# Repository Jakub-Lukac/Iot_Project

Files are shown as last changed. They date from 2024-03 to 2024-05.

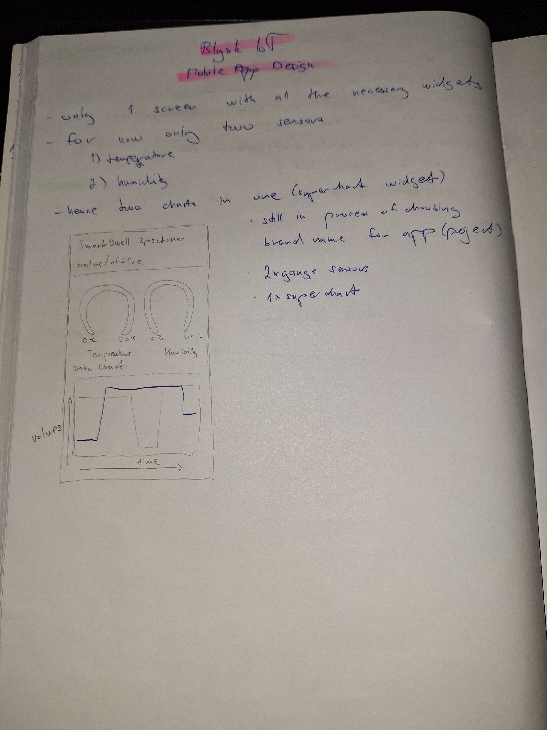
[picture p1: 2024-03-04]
MobileAppDesign/Mobile_App_Files/Low Fidelity.jpg

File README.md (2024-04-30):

# Iot_Project
Arduino and Blynk Project

# Repository structure
As a team, we decided that his GitHub repository would be used for both code as well as all the other documentation like pictures, notes, etc.
It will consist of two folders, Code and Documentation.

# Introduction
The device addresses the need to monitor and maintain quality living conditions in university accommodations and homes, aiming to prevent issues like mold growth. It also benefits elderly individuals living in cold homes by improving their health and social well-being.

# Project Solution
The project creates a room monitoring system for living spaces lacking environmental monitoring. It tracks temperature, humidity, and light levels using microcontrollers and physical sensors, with a screen and optional mobile app for accessibility. Resources are openly available on GitHub for collaboration and transparency.

# Project Requirements
•	Measure temperature.
•	Measure humidity.
•	Measure air quality index.
•	Connect and send data through any specified Wireless connection (Wi-Fi), including eduroam (WPA2 Enterprise).
•	Display current state through display located on the front of the console.
•	Display current state through mobile application

# Reference List
Noëlle Cotter, Eugene Monahan, Helen McAvoy, Patrick Goodman 2012, ‘Coping with the cold – exploring relationships between cold housing, health and social wellbeing in a sample of older people in Ireland’ emerald [Online]. Available from: https://www.emerald.com/insight/content/doi/10.1108/14717791211213607/full/html
[Viewed 8 March 2024]. 
Ahmad Roihan, Ferry Sudarto, Trengginas Cahyo Putro 2018, ‘Internet of Things on Monitoring and Control System in Server Area’ ieeexplore [Online]. Available from: https://ieeexplore.ieee.org/abstract/document/8549759
[Viewed 8 March 2024].

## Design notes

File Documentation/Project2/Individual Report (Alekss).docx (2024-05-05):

Atlantic Technological University, Sligo

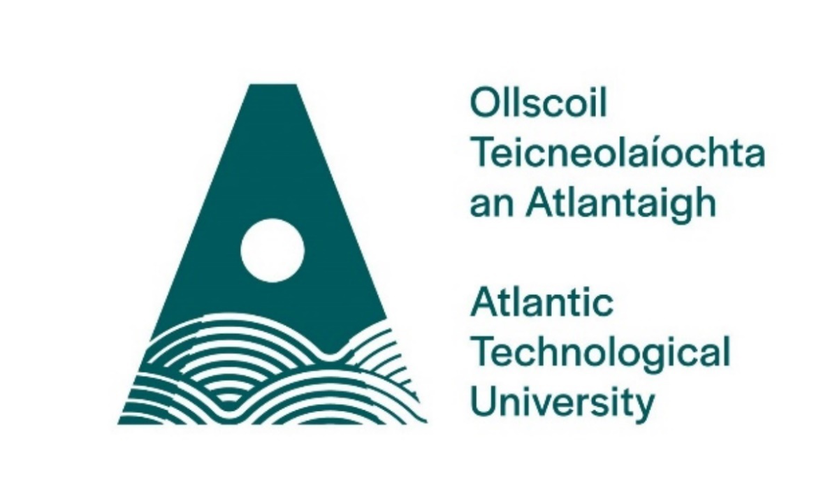
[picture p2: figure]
Obrázok, na ktorom je text, vizitka, snímka obrazovky, písmo Automaticky generovaný popis

# Individual Report

Name: Alekss Belavskis

Student ID: S00253368

Email: s00253368@atu.ie

Course: BSc in Software Development L8

Year: 1

# 1. Team Role:

In my group for Project 2, my main objective was to upgrade the code we used in Project 1. Between project 1 and project 2, we decided to change from using the Arduino Yun to the ESP32 because of its smaller and greater performance.

I continued to use the Arduino IDE during the coding process of the ESP32 for Project 2, as it worked very similarly to the Arduino, aside from some minor code changes. I found Visual Studio to be less clear-cut to setup when working with the ESP32.

I also ended up modifying the previously used Python script for generating the RGB LCD’s colour by adding a cubic interpolation function which addressed some issues with colour transitions, but this feature never ended up being implemented in the ESP code due to the language differences between Python and C.

# 2. Problems Faced:

With project 2, as we decided to use the ESP32 instead of the Arduino Yun, I needed to spend some time adjusting to and learning about how the ESP32 works and how to write code for it. Overall, the code way you write code is very similar for both chips, but there are different libraries required. I also experimented with Visual Studio, but settled with Arduino IDE as it was easier to set up. After adjusting to the small differences in how the ESP works compared to the Arduino Yun, I was ready to add more features to the room monitor.

During my time adding new features to the room monitor, I faced several coding problems I’d eventually come to solve. For example, when I added the functionality of the button to make the display change between showing the temperature and the air quality. I hadn’t initially realized that the button’s state only changed from 0 to 1 while the button was pressed, instead of toggling between 0 and 1 after being pressed and released. I fixed this functionality using logic that compares the current button state to the previous button state. This works by toggling the LCD state only when the last button state and current button state are different.

# 3. Overall Reflection:

I found using GitHub to be very helpful in relation to the coding process. There were times where I wanted to revert part of my code to a previous state, and I could easily do so by looking at previous commits. It also helped us to share our documentation and keep it up to date while we worked on it.

We found that the Arduino Yun did not have very reliable Wi-Fi, because it oftentimes wouldn’t recognize the network I was trying to connect to, and switching to the ESP32 solved this problem. It was much easier to connect to Wi-Fi using the ESP32 in general, and I later found out with some experimenting that it was possible to connect the ESP32 to ‘eduroam’, a WPA2-Enterprise network, using my college credentials. (These credentials were kept safe using a ‘.gitignore’ file)

In conclusion, I’ve really enjoyed working with my group towards a common, and I’m overall satisfied with the product that we created. In the future I’d like to revisit this product idea in my own time to polish it and possibly improve it.

Academic Year: 2023/2024

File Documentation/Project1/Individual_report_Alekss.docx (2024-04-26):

Atlantic Technological University, Sligo

Obrázok, na ktorom je text, vizitka, snímka obrazovky, písmo Automaticky generovaný popis

# Individual Report

Name: Alekss Belavskis

Student ID: S00253368

Email: s00253368@atu.ie

Course: BSc in Software Development L8

Year: 1

# 1. Team Role:

In our group, my primary role revolved around coding and assembling the Arduino room monitoring system. Together, we did a lot of brainstorming about what type of project we wanted to make. After considering all our options, we settled on the room monitor because of its applicability and ease of development and testing.

The coding process involved using the Wokwi emulator to experiment and discover what was possible with the Arduino, before implementing them in the actual hardware. This allowed me to turn our ideas into a functional product. Browsing through code snippets online also allowed me to get new ideas that could be later implemented into our product.

As well as this, I wrote additional scripts in Python that would allow for manual testing of all possible input/output cases of the Arduino sensors. For example, a test that would input a temperature number, and output a colour for the backlight. This saved time as we could verify the Arduino code was working correctly without relying solely on physical sensors to test it.

# 2. Problems Faced:

The first major hurdle we faced was thinking of a suitable project idea. While we had several ideas, for example a hiking assistant, we felt that most of them weren’t very practical, or easy for us to create and test. This is the reason we ended up settling on the room monitor, as it was something we were all capable of building together with the amount of time we had, and this product has utility in both residential and professional settings.

There were several minor problems faced during the development of the code for the Arduino Yun that were solved in the end, but the notable one occurred during our integration of Blynk into the Arduino. The code snippet we found for Blynk integration took up too much of the Arduino Yun’s storage to be able to compile and upload. What ensued was a lot of research into using the SD card as additional storage, or to extend the Arduino’s storage, but in the end, we found a code snippet for Blynk that was suitable for the Yun, and our product demo.

# 3. Overall Reflection:

Arduino development was something completely novel to me, so I enjoyed learning how to build them, code them and solve whatever problems I faced.

In hindsight, I felt that we didn’t leverage Trello to its fullest potential, partly due to our small group size and most of our communication taking place in person, with occasional text messages. I think we could have all created a Trello board structure which makes sense to all of us and discuss it in a way where we all understand and can make use of it. I also realized the importance of scheduling regular meetings, as it significantly sped up our productivity and project progression.

After the problems we faced integrating Blynk into the Arduino Yun, we are considering using the ESP8266 board, as it also has built-in WI-FI, and has plenty of documentation of using it with Blynk. I believe this change will make our product development process work smoother.

In conclusion, my involvement in this group has been both exciting and enriching for me, and I hope to make even more progress in the coming weeks.

Academic Year: 2023/2024

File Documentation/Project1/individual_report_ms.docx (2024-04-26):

Atlantic Technological University, Sligo

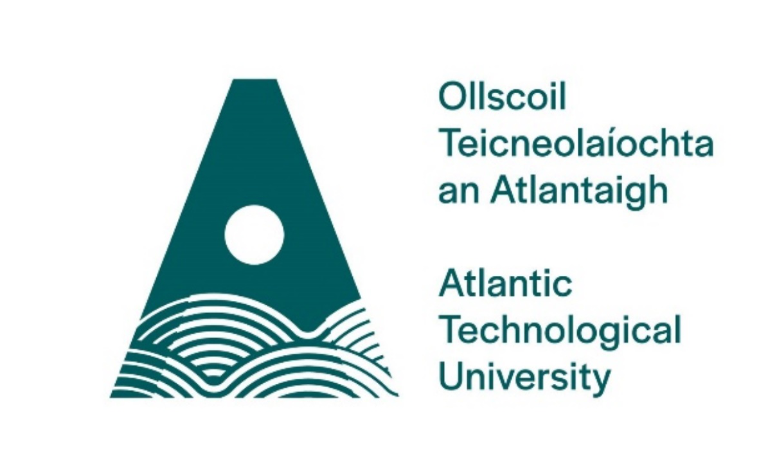
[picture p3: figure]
Obrázok, na ktorom je text, vizitka, snímka obrazovky, písmo Automaticky generovaný popis

# Internet of Things

# Room Monitoring System

# Individual report

## By Martin Strelec

# 1. Role in the project

I had a part in this project as a designer of our housing for the room monitoring system as well as the person who decides how the whole system will be hardwired together. These roles allowed me to design the appearance of the final product, decide on what components will the product contain and generally help our team to achieve the best quality product possible.

# 2. What I have learned

For this project, communication was the most important thing. Even though we were collaborating well, there were still lots of disagreements and opposing thoughts due to each of us being themselves and wanting something different than the others. However, we settled on compromises that in the end made the final product and everyone in the team was happy. The other important thing was scheduling the meetings. It did not seem so at the start but further on I realized that to have at least a prototype would require us to meet more often than in the time during IoT classes. After figuring this out, it was a lot easier, and we all felt like the development was progressing a lot quicker than before.

# 3. Problems and their solution

One of the problems we faced was that we were not able to use the provided code for the standard microcontroller Arduino YÚN. The Blynk app code that was supposed to run on the device was in fact too large to compile and upload to Arduino. After a bit of research and hustle with the Arduino, our lecturer tried to help us by providing different code that was tested and worked well previously. This option was in fact very helpful but in the end, we decided to go a different way. Instead of choosing Arduino YÚN we opted to use another microcontroller with built-in Wi-Fi called ESP8266. We chose this board because it was used by the Blynk team and had tons of resources and guides on how to get the app up and running. This turned out to be a great decision because it allowed us to use the same components as before but with a smaller microcontroller that was better supported. In the future this will allow us to design a more compact and more functional case for the whole project.

Academic Year: 2023/2024

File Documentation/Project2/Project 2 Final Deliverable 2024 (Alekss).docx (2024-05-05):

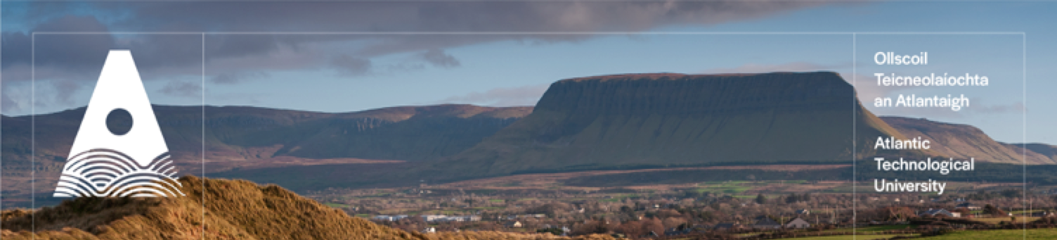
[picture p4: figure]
Inserting image...
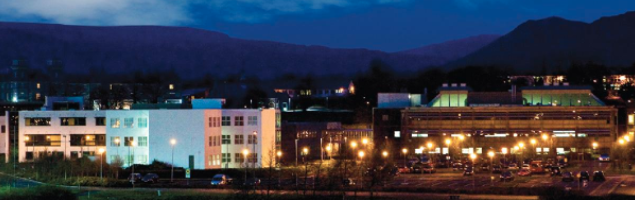
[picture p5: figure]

Internet of Things
– Final Project Report Update, Critical Analysis, Risk Analysis & Poster Submission – due May 3rd

## 1. Final Project Report Update

Prepare an update of your original report (Turn on Track Changes) Internet & Machine Learning Functionality:

This submission should feature a further refinement or inclusion of some Internet functionality e.g. data logged in a spreadsheet, email notifications, a Blynk app, or Web User Interface etc. and should include:

a) Description of Internet functionality planned, including details of APIs used (e.g. PushingBox, Blynk, REST Web Service based UI)
b) Secondary research, on similar internet projects you have found online, to support your implementation and validate the idea
c) Ideas for the potential future application of Machine Learning to enhance your project functionality – specify a Machine Learning algorithm and a description of the data you would use
d) Video of your final working prototype

## 2. Prepare an academic style poster* presenting the Final Implementation of your Project

* Academic Poster Summarising your Project - submit in PowerPoint or PDF format

If you Google ‘Academic Poster Template’ you will find many to choose from in PowerPoint e.g. here
(https://www.makesigns.com/SciPosters_Templates.aspx)Also, there are some great guides to creating academic posters here (http://www.colby.edu/acits/student-academic-poster-guidelines/) from Colby College.

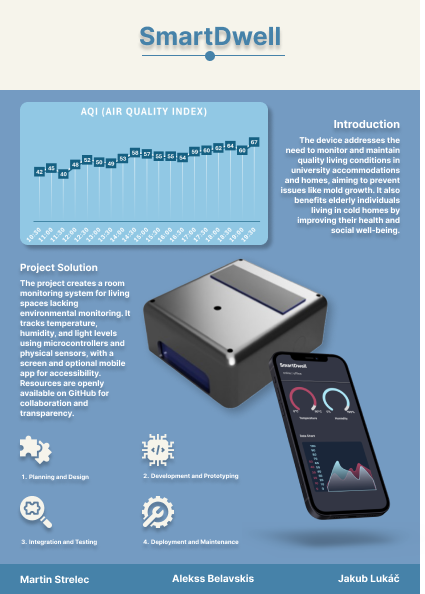
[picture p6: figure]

## 3. Critical Analysis of your Application

Reflect on and include here your Critical Analysis from Lab 6

Internet of Things

Critical Analysis

bit.ly/3vTYAA2

Name | Alekss Belavskis
Date | 26/04/2024
Student No | S00253368
Student Email | s00253368@atu.ie

### Critical Analysis - see slides here (https://docs.google.com/presentation/d/193MMMz7EaoHWorLezZqeiO9gTh3cI20Jm06GoyJhtnw/edit?usp=sharing)

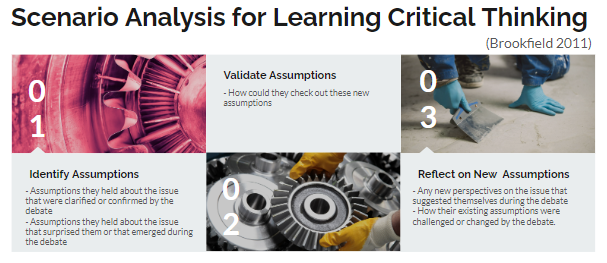
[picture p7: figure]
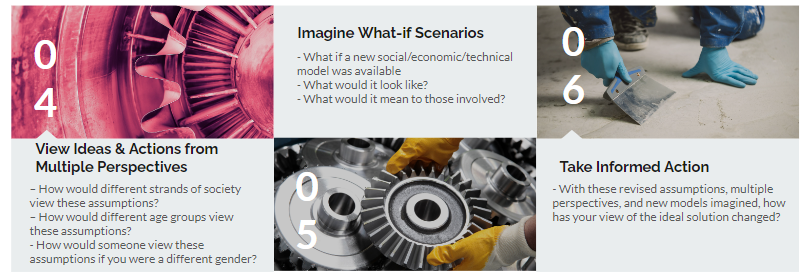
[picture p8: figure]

### e) Draw the variables in your system in the format of a Bayesian Network

1. Draw the node you are trying to optimise in your system - e.g. OPTIMISE HYDRATION
2. Draw each node that will influence this dependent variable
3. Draw edges between nodes that influence each other
4. Calculate percentages of probabilities for each node (should add up to 100%)

### Individual Diagram

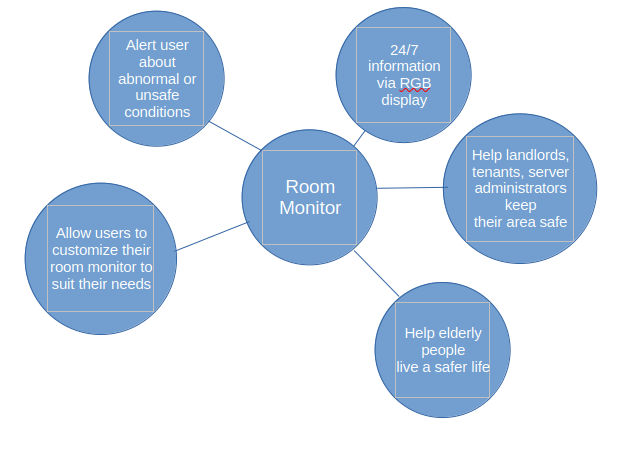
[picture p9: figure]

Group Diagram

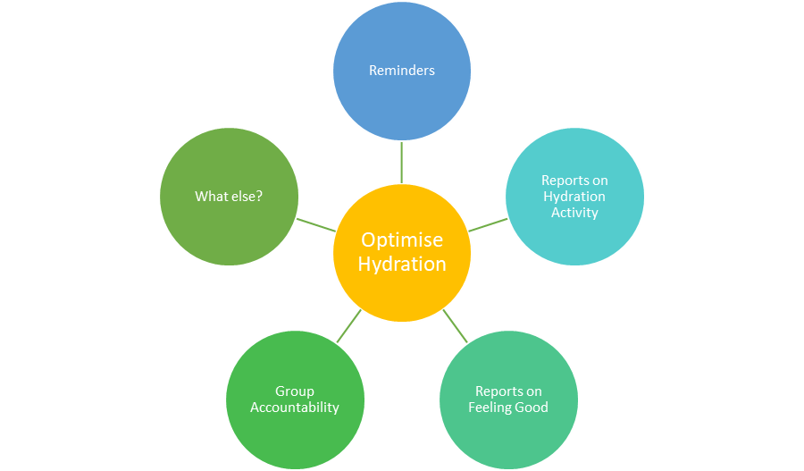
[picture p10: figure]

Overall System | AI Elements of the system
What *effect* does your system have? On individuals? Worry-free and comfortable living experience On society? Safer and more reliable infrastructure

### 2. Identify Assumptions

What assumptions did you make in designing your system?

Overall System | AI Elements of the system
1. People would like to keep a room monitor in their room 2. People will know how to set up and use the room monitor 3. People are interesting in tracking the conditions of their room 4. People would like to make their living conditions easier 5. People are willing to pay for a room monitor 6. The room monitor provides a practical benefit for the users

### 3. Validate Assumptions

How could you check whether these assumptions are true?

Overall System | AI Elements of the system
1. Survey how many people use/want monitoring gadgets 2. Conduct user testing to see how able they are to set it up 3. Survey people to see if they would like to track the conditions of their room 4. Survey people to see if they are affected negatively or positively by their living conditions 5. Survey to see how much people are willing to pay for a room monitor 6. Ask people who own room monitoring devices about what it provides them

### 4. Reflect on New Assumptions

What new insights have you gained by identifying and validating your assumptions?

Overall System | AI Elements of the system
1. We know that we’re providing for a demand in the market. 2. We should include a user manual with the product to help set it up 3. There is an interest for users to buy a simple monitoring device in their room 4. People are often too warm/too cold in their homes and want an easy way to control it 5. There are people who are willing to pay for a room monitor 6. A room monitoring device can save people’s time and money

### 5. Consider Different Perspectives

How does your system design, ideas & actions look from Multiple Perspectives e.g. perspective people of different ages, different socioeconomic backgrounds, different genders, different types of business people, different types of investors, different nationalities, differently abled people etc?

Overall System | AI Elements of the system
1. People from countries who are not used to the temperature may be more inclined to control it to a more comfortable level 2. Accessible to all nationality groups (Celsius in Europe, Fahrenheit in America) 3. Usability for people in both home and professional settings (server rooms) 4. Accessible controls for differently abled individuals 5. Availability in multiple languages so that non-English speakers can also use the product 6. User-friendly interface that by extension helps neuro-diverse people

### 6. Imagine What-if Scenarios

Can you re-imagine your system, or the environments and people using, it to unlock new creative possibilities? What do you imagine could be possible in the future?

Overall System | AI Elements of the system

1. The room monitor could control a central heating system in your house

2. The room monitor could make predictions about future conditions

3. The room monitor could control smart lighting systems in your home based on climate data

4. The room monitor could create different kinds of alerts or contact certain people in the case of detection of adverse conditions

5. The room monitor could integrate with smart locks or security cameras, to enhance automation and safety

6. The room monitor could connect to a healthcare service and track environmental conditions that could impact health, such as air quality or temperature. This can provide reassurance for elderly or other vulnerable people.

### 7. Take Informed Action

Having gone through this Critical Analysis exercise, what would you change about your system and why?

Overall System | AI Elements of the system

1. We would enhance the accessibility of the room monitor, for example, by adding voice controls.

2. We would expand the language and regional options available in our room monitor and mobile app

3. We would make sure the room monitor has appropriate security so that it can’t be exploited as a weak link in a network of devices.

4. We would implement machine learning to be able to predict the future climate or lighting conditions in a room.

5. We would create an online forum where users of the product can contribute with discussions and ideas that we can use to improve the product for them.

6. We would include a physical and digital user manual to help users with setting up, maintaining, and configuring the product.

### 8. Draw a refined version of your BN Diagram from Step 1 - taking into account your Critical Analysis in Steps 2-7

5. Draw the node you are trying to optimise in your system
6. Draw each node that will influence this dependent variable
7. Draw edges between nodes that influence each other
8. Calculate percentages of probabilities for each node (should add up to 100%)

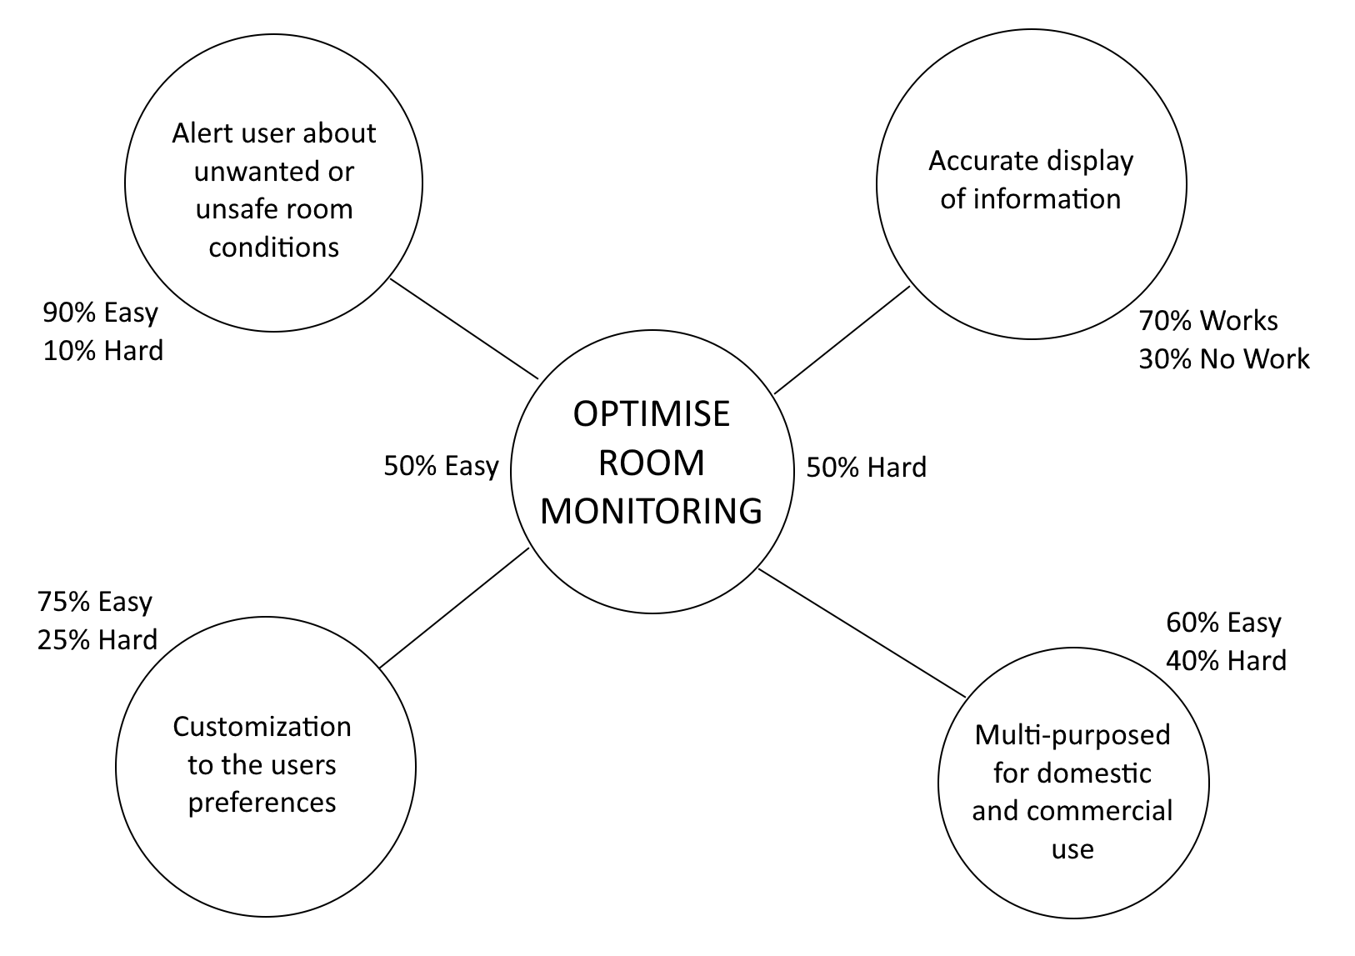
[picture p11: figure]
A diagram of a room monitoring

## 4. Ethics Risk Analysis of the future of your Application

Use the Ethical OS (https://atlantictu-my.sharepoint.com/:b:/g/personal/mary_loftus_atu_ie/EVddukJk2zlLmQmdh9OJEjQBXu0QCAhgq1lPiRlPmGUqtw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) to evaluate whether your project poses future risks, by scoring your project for likelihood and impact in each Risk Zone e.g.

Project Name
Risk Zone | Risk Descriptions | Likelihood (Score 1-5) | Impact (Score 1-5) | Risk Score Likelihood x Impact | Risk Remediation Actions Required
Zone 1 - Truth, Disinformation, Propaganda | Unreliable code or sensors could display inaccurate information | 4 | 4 | 16 | Frequent updates and testing. Replace sensors if faulty.
Zone 2 - Addiction & the Dopamine Economy | Could develop addiction to clicking the button and receiving feedback via LCD | 1 | 2 | 2 | Implement cool down for if the button is pressed too many times in a short period of time. This will help prevent the user from receiving a surplus of dopamine from pressing the button.
Zone 3 - Economic & Asset Inequalities | The manufacturers of our parts could be underpaid and/or in poor conditions | 3 | 3 | 9 | Verify the manufacturers of our products to see if the conditions of labour are ethical.
Zone 4 - Machine Ethics & Algorithmic Biases | Historical climate data could be used to make predictions about the future, but this cannot be relied on to be accurate | 4 | 4 | 16 | Make sure all factors are taken into account when making climate predictions. Judging the temperature of the next day based on one day can’t be relied on, but the average temperature of each month could be predicted with a year’s of data.
Zone 5 - Surveillance State | The users might not trust that the product isn’t watching or listening to them in some way. | 1 | 5 | 5 | Make sure the product is easy to disassemble and examine, and make schematics available online.
Zone 6 - Data Control & Monetization | The product could collect long-term data about the user’s home which could be used to make assumptions about that person. | 4 | 5 | 20 | Data needs to be kept secure from being intercepted or breached by anyone other than the owner of the product. Ensure user is using a secure email and password,
Zone 7 - Implicit Trust & User Understanding | The user might not be fully aware of what data the product is storing. | 2 | 3 | 6 | Provide a manual that explains how to use the product and manage the information it collects to make sure they are fully aware.
Zone 8 - Hateful & Criminal Actors | If our product is controlling elements of the household such as lighting or heating, it is at risk of being hacked into. | 3 | 5 | 15 | Ensure the user and devices are using strong passwords, and use encrypted communication between devices. Don’t allow easy direct access to the electronics code.

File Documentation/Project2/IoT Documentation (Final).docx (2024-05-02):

Atlantic Technological University, Sligo

Obrázok, na ktorom je text, vizitka, snímka obrazovky, písmo Automaticky generovaný popis

# Internet of Things

# Room Monitoring System

Team members:

Jakub Lukac s00255726@atu.ie

Martin Strelec s00256070@atu.ie

Alekss Belavskis s00253368@atu.ie

GitHub link: https://github.com/Jakub-Lukac/Iot_Project

Trello link: https://trello.com/b/5Fzlq8Bj/main

Table of Contents

# 1. Explaining the Problem

As university students, our experiences often lead us to living in various places. For example, on university campuses. These accommodations often present unfamiliar problems and challenges. This includes the state and quality of the accommodation, which can affect our health and well-being. It is for this reason we decided to develop a device that allows the students, and most importantly, landlords, to monitor the main aspects that are essential in maintaining quality accommodation. These aspects include the amount of light that enters the room, the overall temperature, and humidity. These aspects can be controlled to prevent mold growth, or other undesirable living conditions.

Due to our firsthand experience in these environments, we know how hard it can be, and how it affects our well-being. In fact, digging deeper, we found out that it is not only us students and landlords that could benefit from this. Elderly people, who are particularly susceptible to substandard living conditions, would also hugely benefit from such a device. We found compelling evidence regarding the impact of cold housing on a sample of elderly people. This article discusses the health and social impacts of living in cold homes for older people in Ireland, highlighting the link between poor housing conditions and adverse health effects, such as respiratory and cardiovascular issues. It also emphasizes the financial strain and social isolation older individuals may face due to the challenges of heating their homes adequately. The research outlines the importance of addressing these issues through interventions, such as improving household energy efficiency, to mitigate the negative health and social consequences of living in cold homes. ( Noëlle Cotter (https://www.emerald.com/insight/search?q=Noëlle%20Cotter) et al 2012)

Not only is this system useful in residential settings, but it can also be useful in monitoring the environments surrounding sensitive electrical equipment, such as servers. These devices are very delicate, and for their unobstructed operation, they need to be in a specific place with specific surrounding conditions. Another article mentioned their use of a similar control system to ours in a server area to enhance the efficiency of their monitoring and security. Their system can provide real-time monitoring and automatic responses to potential hazards in the server room. This solution aims to streamline monitoring tasks, improve security measures, and ensure timely responses to critical events within the server area, ensuring proper functionality. (Ahmad Roihan, Ferry Sudarto, Trengginas Cahyo Putro 2018)

# 2. Summary of Project Solution

Our project aims to address the lack of environmental monitoring systems in various living spaces, such as university accommodation and elderly homes, that could benefit the wellbeing of its residents. Our room monitoring system will be able to track the temperature, humidity, and light levels of the room it's placed in.

This device will employ a microcontroller such as the Arduino YÚN or the ESP8266, connected to physical sensors that can send information about the environment to the microcontroller. Lastly, it will use a screen to display this information to the user, and a button or touch pad to customize what appears on the display. This screen features an RGB backlight which allows us to change the colour of the display depending on the temperature. This will help those with impaired vision to know the temperature without reading the figures on the display. All of this will be physically encased in a shell which will keep the electronic parts safe from damage and prevent temperament of the device.

For additional accessibility, we will develop an optional mobile app that will connect to the device and display all the same information available on the display. The mobile app will operate by communicating with an online database, such as Firebase, with which our microcontroller will share its sensor data.

In developing our solution, sustainability and security are both big priorities. Our project resources will be openly available on GitHub, a code sharing platform, which ensures easy collaboration between members. Additionally, as the code is public, it will allow users to have peace of mind knowing that the device isn’t doing anything malicious. It will also allow other developers to contribute code, such as new additions and fixes, to our codebase. We will ensure security of the device and mobile app by encrypting all the information sent between them. Most importantly, we will maintain the device’s security and keep it up to date.

This solution can extend not only to residential housing, but also to sensitive environments like server rooms. Looking ahead, we envision several enhancements to our device. For example, we could implement an additional display to show the forecast, which we would take from the internet. We could also add an air quality sensor to measure carbon dioxide levels, something that could occur from poor ventilation. This could notify the user that they should open a window or otherwise increase ventilation of the room and would benefit their health and well-being.

# 3. List of Project Requirements

Our project had to be designed with following requirements:

The system should:

- Measure temperature.
- Measure humidity.
- Measure air quality index.
- Connect and send data through any specified wireless connection (Wi-Fi), including eduroam (WPA2 Enterprise).
- Display current state through display located on the front of the console.
- Display current state through mobile application.

# 4. Initial Design

The first thing we needed to do was to sketch the initial design of the device. That includes the hardware setup and components used. After this we could start developing the code and sketching the initial design for the housing.

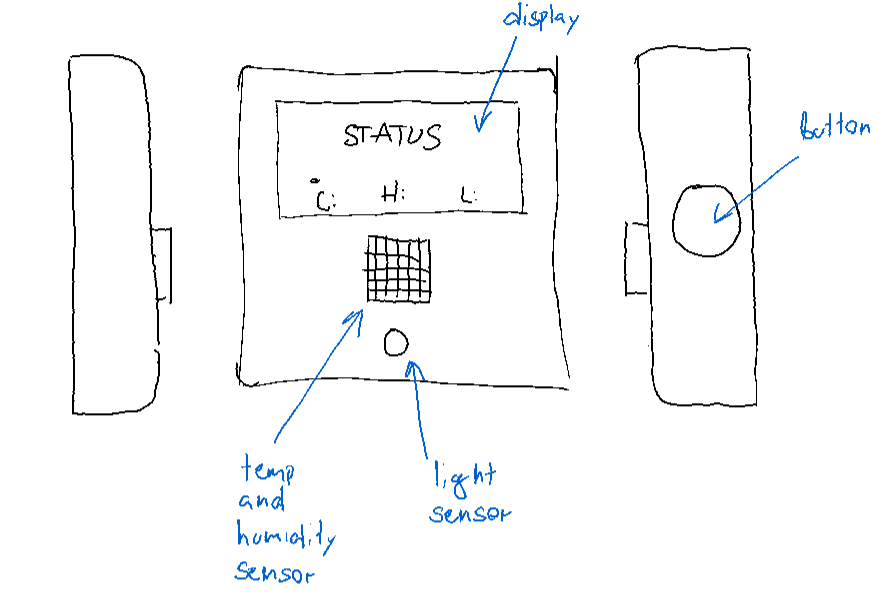
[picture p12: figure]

Picture 1 Initial housing design

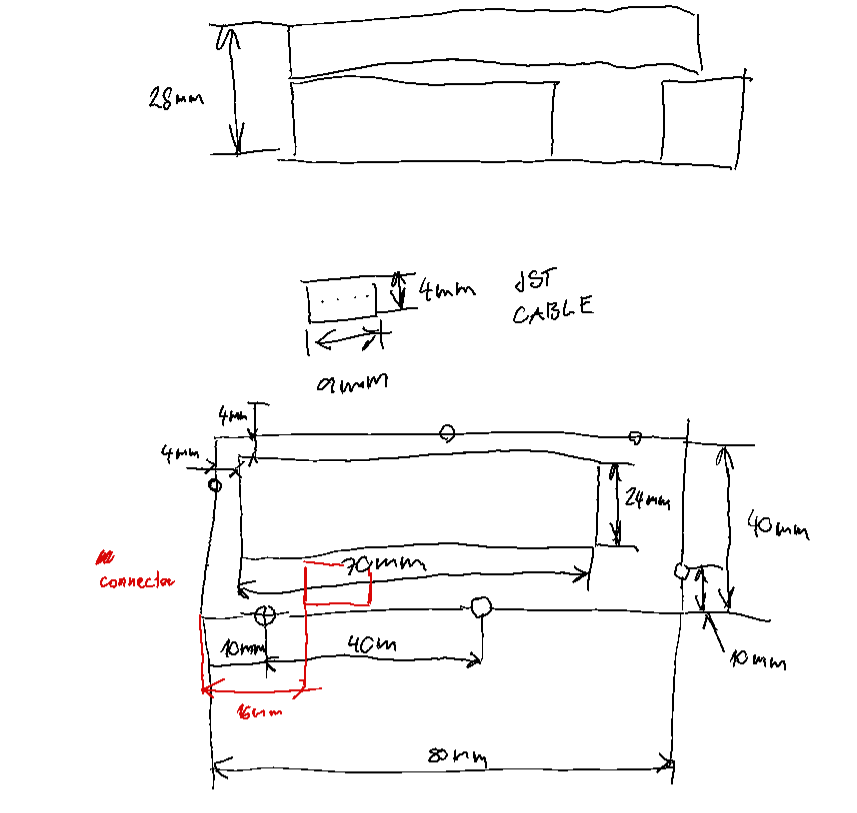
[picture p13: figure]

Picture 2 Dimension sketch for the components

As an initial sketch of app design, we made a low fidelity design of our app. It was then later used to form the final look of the app.

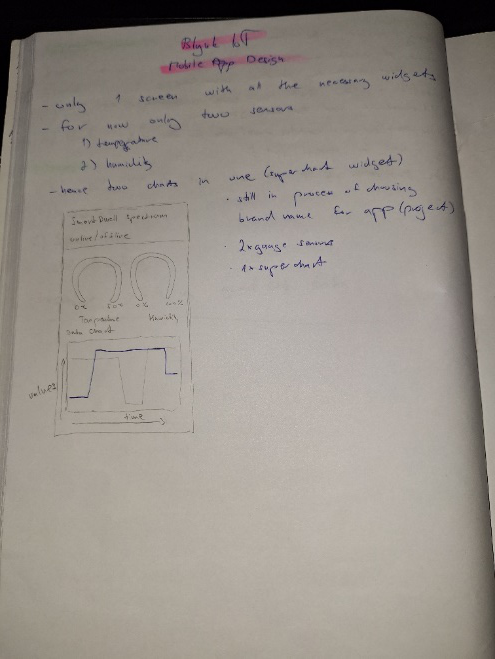
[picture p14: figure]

Picture 3 Low Fidelity Design for mobile app

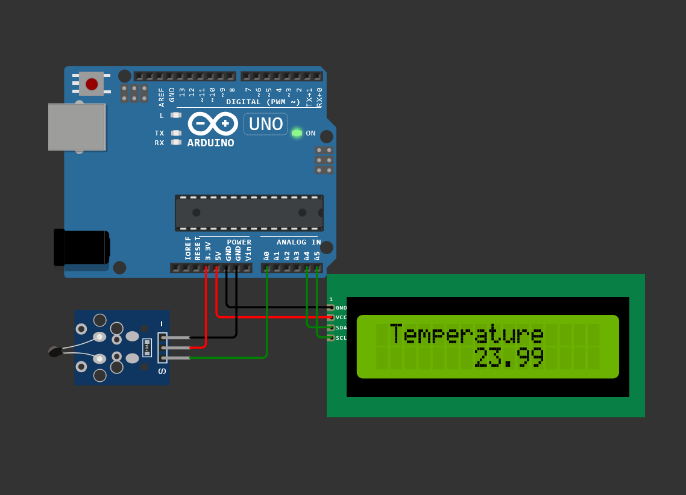
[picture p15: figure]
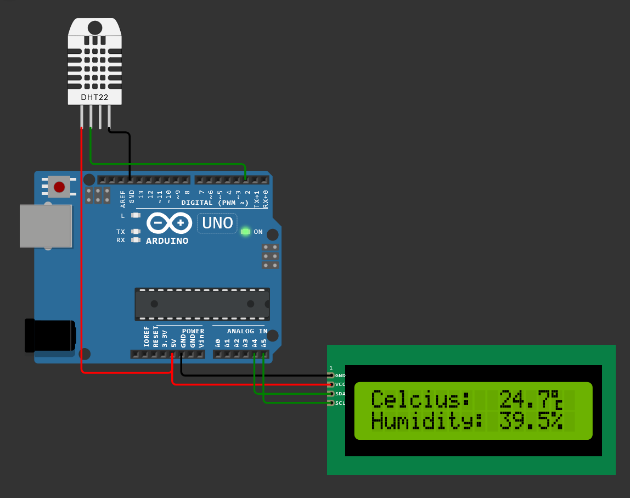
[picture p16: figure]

We decided to use the code provided by Blynk to process our sensor data. In case of insufficient processing power and limited memory provided by the Arduino YÚN used as a main component in our project we thought of another approach eliminating these factors. We discovered that we could use a different controller board called ESP32 with Firebase database to store real time data thanks to Firebase API. The ESP32 was chosen instead of the Arduino YÚN because it has better support, and it is more suitable for our application.

Picture 4 Wiring diagram 2

Picture 5 Wiring diagram 1

In the event of using the ESP32 controller we had two options. Either use the first proposed Blynk app and its code to maintain the controller code ran on the ESP32 and the mobile app. Or we could develop a new mobile application using Flutter framework for both iOS and Android system with Firebase real-time database and Firebase API which overall has great compatibility with Flutter.

# 5. Implementation Plan

To realize this idea of a project we needed a couple of things. First was the hardware and all the parts necessary for basic functionality of the system. That includes the following list of parts that contain both viable options described in the Initial Design section.

## Option A

- Arduino YÚN
- Arduino YÚN shield (provided from Grove kit v3.1)
- LCD screen (provided from Grove kit v3.1)
- Generic button (provided from Grove kit v3.1)
- Air quality sensor (provided from Grove kit v3.1)
- Temperature sensor (provided from Grove kit v3.1)

JST cables for connecting all the components (provided from Grove kit v3.1)

## Option B

- ESP32
- LCD screen (provided from Grove kit v3.1)
- Generic button (provided from Grove kit v3.1)
- Air quality sensor (sourced externally)
- DHT11 Temperature and Humidity sensor (sourced externally)
- JST cables for connecting all the components (provided from Grove kit v3.1)
- Soldering iron kit (sourced externally)

For both cases we designed a 3D printed housing that will accommodate all the hardware described in either option.

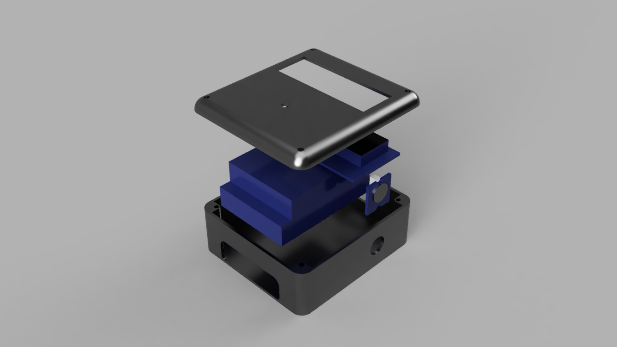
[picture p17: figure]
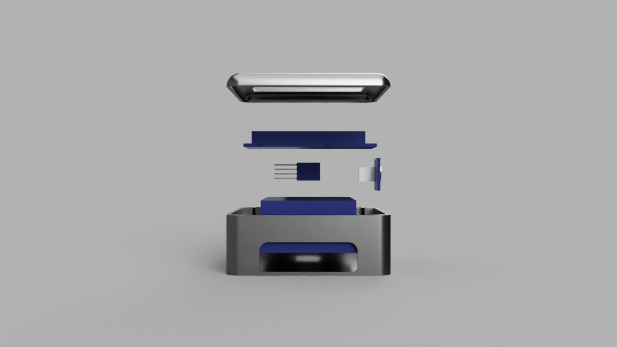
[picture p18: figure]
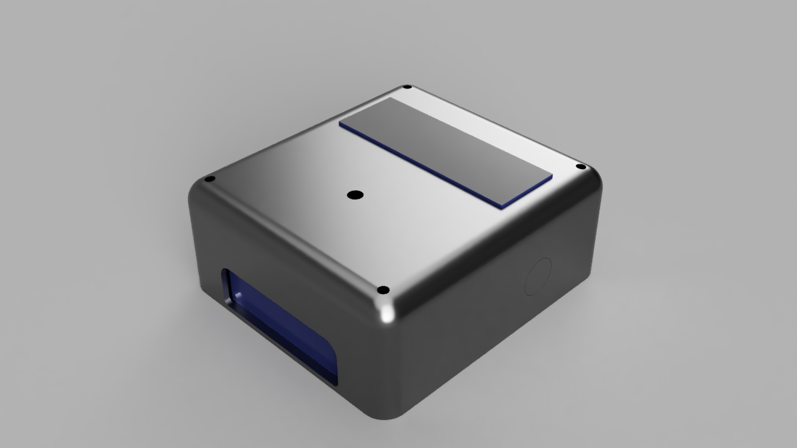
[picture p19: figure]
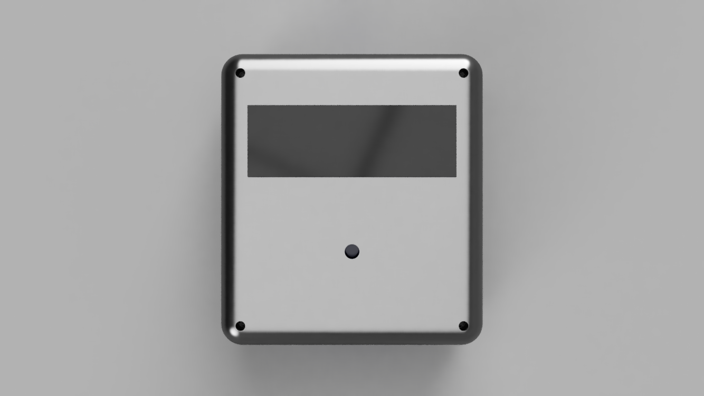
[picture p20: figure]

Picture 6 Renders of final design

The API will be used only with option B being the Firebase API which is described in more detail in the Initial Design section.

The following code snippets will be used in the actual project. They refer to implementation of Grove kit’s temperature and humidity sensors as well as DHT sensors with build in methods for measuring temperature and humidity. Other code snippets also include implementation of LCD display and setting up the connection between Arduino YÚN and Blynk mobile application, and lastly connecting the Arduino YÚN to Wi-Fi.

## Code Example #1

#define BLYNK_TEMPLATE_ID "TMPL4fnh6fOfH"

#define BLYNK_TEMPLATE_NAME "TESTING"

#define BLYNK_AUTH_TOKEN "euvMzHZrgcq9EjXGBV3cYtoN-rjmSNgo"

/* Comment this out to disable prints and save space */

#define BLYNK_PRINT Serial

#include <BlynkRpcClient.h>

#include <SPI.h>

#include <WiFi101.h>

#include <BlynkSimpleWiFiShield101.h>

#include <Wire.h>

#include "rgb_lcd.h"

// Your WiFi credentials.

// Set password to "" for open networks.

char ssid[] = "DobryDen";

char pass[] = "DobryDen";

BlynkTimer timer;

float celsius;

// This function is called every time the Virtual Pin 0 state changes

BLYNK_WRITE(V0)

{

// Set incoming value from pin V0 to a variable

int value = param.asInt();

// Update state

Blynk.virtualWrite(V1, value);

}

// This function sends Arduino's uptime every second to Virtual Pin 2.

void myTimerEvent()

{

// You can send any value at any time.

// Please don't send more than 10 values per second.

Blynk.virtualWrite(V2, celsius);

}

rgb_lcd lcd;

const float BETA = 3950;

void setup()

{

Serial.begin(115200);

Blynk.begin(BLYNK_AUTH_TOKEN, ssid, pass);

timer.setInterval(1000L, myTimerEvent);

lcd.begin(16, 2);

lcd.setRGB(255, 0, 255);

delay(1000);

}

void loop()

{

Blynk.run();

timer.run();

int analogValue = analogRead(A0);

celsius = 1 / (log(1 / (1023. / analogValue - 1)) / BETA + 1.0 / 298.15) - 273.15;

lcd.setCursor(0, 1);

lcd.print(celsius);

}

## Code Example #2

#include "DHT.h"

#define DHTPIN 2

#define DHTTYPE DHT22

DHT dht(DHTPIN, DHTTYPE);

#include "LiquidCrystal_I2C.h"

LiquidCrystal_I2C lcd(0x27, 20, 4);

uint8_t deg[8] = {

0b11100,

0b10100,

0b11100,

0b00000,

0b00111,

0b00100,

0b00100,

0b00111,

};

uint8_t percent[8] = {

0b11000,

0b11001,

0b00010,

0b00100,

0b01000,

0b10011,

0b00011,

0b00000,

};

void setup() {

Serial.begin(9600);

Serial.println(F("DHTxx test!"));

dht.begin();

lcd.init();

lcd.backlight();

lcd.setCursor(0, 0);

lcd.print("Celsius:");

lcd.setCursor(0, 1);

lcd.print("Humidity:");

}

void loop() {

delay(2000);

float h = dht.readHumidity();

float t = dht.readTemperature();

float f = dht.readTemperature(true);

float hif = dht.computeHeatIndex(f, h);

float hic = dht.computeHeatIndex(t, h, false);

uint8_t deg2[8] = {0};

uint8_t percent2[8] = {0};

for (int i = 0; i < 8; i++) {

deg2[i] = deg[i];

lcd.createChar(3, deg2);

percent2[i] = percent[i];

lcd.createChar(4, percent2);

delay(100);

}

delay(500);

lcd.setCursor(10, 0);

lcd.print(t);

lcd.setCursor(14, 0);

lcd.print("\x03");

lcd.setCursor(10, 1);

lcd.print(h);

lcd.setCursor(14, 1);

lcd.print("\x04");

}

## Code Example #3

#include "LiquidCrystal_I2C.h"

LiquidCrystal_I2C lcd(0x27, 20, 4);

const float BETA = 3950;

void setup() {

Serial.begin(9600);

lcd.init();

lcd.backlight();

lcd.setCursor(1, 0);

lcd.print("Temperature");

}

void loop() {

int analogValue = analogRead(A0);

float celsius = 1 / (log(1 / (1023. / analogValue - 1)) / BETA + 1.0 / 298.15) - 273.15;

lcd.setCursor(7, 1);

lcd.print(celsius);

}

## Code Example #4

#define BLYNK_TEMPLATE_ID "TMPL4fnh6fOfH"

#define BLYNK_TEMPLATE_NAME "TESTING"

#define BLYNK_AUTH_TOKEN "euvMzHZrgcq9EjXGBV3cYtoN-rjmSNgo"

/* Comment this out to disable prints and save space */

#define BLYNK_PRINT Serial

#include <BlynkRpcClient.h>

#include <SPI.h>

#include <WiFi101.h>

#include <BlynkSimpleWiFiShield101.h>

#include <Wire.h>

#include "rgb_lcd.h"

// Your WiFi credentials.

// Set password to "" for open networks.

char ssid[] = "DobryDen";

char pass[] = "DobryDen";

BlynkTimer timer;

float celsius;

// This function is called every time the Virtual Pin 0 state changes

BLYNK_WRITE(V0)

{

// Set incoming value from pin V0 to a variable

int value = param.asInt();

// Update state

Blynk.virtualWrite(V1, value);

}

// This function sends Arduino's uptime every second to Virtual Pin 2.

void myTimerEvent()

{

// You can send any value at any time.

// Please don't send more that 10 values per second.

Blynk.virtualWrite(V2, celsius);

}

rgb_lcd lcd;

const float BETA = 3950;

void setup()

{

Serial.begin(115200);

Blynk.begin(BLYNK_AUTH_TOKEN, ssid, pass);

timer.setInterval(1000L, myTimerEvent);

lcd.begin(16, 2);

lcd.setRGB(255, 0, 255);

delay(1000);

}

void loop()

{

Blynk.run();

timer.run();

int analogValue = analogRead(A0);

celsius = 1 / (log(1 / (1023. / analogValue - 1)) / BETA + 1.0 / 298.15) - 273.15;

lcd.setCursor(0, 1);

lcd.print(celsius);

}

Final Code

#define BLYNK_PRINT Serial

#include "secrets.h"

#include <WiFi.h>

#include <WiFiClient.h>

#include <BlynkSimpleEsp32.h>

#include "esp_wpa2.h"

#include <DHT.h>

#include <Wire.h>

#include "rgb_lcd.h"

#define MQ135PIN A4 // Analog pin for MQ-135 air quality sensor

#define DHTPIN A0 // Digital pin for DHT-11 temperature/humidity sensor

#define DHTTYPE DHT11

#define CONTROLLERPIN A27 // Analog pin for button/rotary controller to control the RGB LCD

DHT dht(DHTPIN, DHTTYPE); // Types: DHT11, DHT22 (AM2302, AM2321), DHT21 (AM2301)

rgb_lcd lcd;

BlynkTimer timer;

uint8_t degreeSymbol[8] = { 0b11100, 0b10100, 0b11100, 0b00000, 0b00111, 0b00100, 0b00100, 0b00111 };

float celcius;

float humidity;

int airQuality;

int button = 0;

String getWifiStatus(int status) {

switch(status) {

case WL_IDLE_STATUS: return "WL_IDLE_STATUS";

case WL_SCAN_COMPLETED: return "WL_SCAN_COMPLETED";

case WL_NO_SSID_AVAIL: return "WL_NO_SSID_AVAIL";

case WL_CONNECT_FAILED: return "WL_CONNECT_FAILED";

case WL_CONNECTION_LOST: return "WL_CONNECTION_LOST";

case WL_CONNECTED: return "WL_CONNECTED";

case WL_DISCONNECTED: return "WL_DISCONNECTED";

}

}

void setBacklightColour(float input, int min, int mid, int max) {

int r, g, b;

if (input <= min) {

r = 0;

g = 0;

b = 255;

} else if (input <= mid) {

r = 0;

g = map(input, min, mid, 0, 255);

b = 255 - g;

} else {

r = 255;

g = map(input, mid, max, 255, 0);

b = 0;

}

lcd.setRGB(r, g, b);

}

void printValueToLCD(int value, String title, String symbol, int min, int mid, int max) {

lcd.clear();

setBacklightColour(value, min, mid, max);

lcd.setCursor(0, 0);

lcd.print(title);

lcd.setCursor(2, 1);

lcd.print(value);

lcd.setCursor(5, 1);

lcd.print(symbol);

}

void mainTimer() {

// celcius = 15.6;

celcius = dht.readTemperature();

// humidity = 40.1;

humidity = dht.readHumidity();

if (isnan(celcius) || isnan(humidity)) {

Serial.println("Failed to read from DHT sensor!");

}

// airQuality = 30;

airQuality = analogRead(MQ135PIN);

Blynk.virtualWrite(V2, celcius);

Blynk.virtualWrite(V3, humidity);

Blynk.virtualWrite(V4, airQuality);

Serial.print("Celcius: ");

Serial.print(celcius);

Serial.println(" 'C");

Serial.print("Humidity: ");

Serial.print(humidity);

Serial.println(" %");

Serial.print("Air Quality: ");

Serial.print(airQuality);

Serial.println(" AQI");

// button = 0;

button = analogRead(CONTROLLERPIN);

if (button < 80) {

printValueToLCD(celcius, "Temperature", "\x03", -10, 15, 50);

} else if (button <= 160) {

printValueToLCD(humidity, "Humidity", "%", 0, 50, 100);

} else if (button > 160) {

printValueToLCD(airQuality, "Air Quality", "AQI", 0, 250, 500);

}

}

void connectToWifi() {

int status = WL_IDLE_STATUS;

Serial.print("\nConnecting to network: ");

Serial.println(WIFI_SSID);

Serial.println(getWifiStatus(status));

WiFi.disconnect(true); // Disconnect from Wi-Fi to set new Wi-Fi connection

WiFi.mode(WIFI_STA); // Set Wi-Fi mode

WiFi.begin(WIFI_SSID, WPA2_AUTH_PEAP, EAP_ANONYMOUS_IDENTITY, EAP_IDENTITY, EAP_PASSWORD);

// WiFi.begin(WIFI_SSID, WIFI_PASSWORD);

int counter = 0;

while (WiFi.status() != WL_CONNECTED) {

if (counter++ >= 60) { ESP.restart(); }

status = WiFi.status();

Serial.print(getWifiStatus(status));

pinMode(CONTROLLERPIN, INPUT);

Serial.println("...");

delay(500);

}

Serial.println("");

Serial.println(F("Connected!"));

Serial.println(F("Local ESP32 IP: "));

Serial.println(WiFi.localIP());

}

void setup() {

Serial.begin(115200);

connectToWifi();

pinMode(CONTROLLERPIN, INPUT);

lcd.begin(16, 2, 0);

lcd.setRGB(0, 255, 0);

lcd.createChar(3, degreeSymbol);

dht.begin();

Blynk.begin(BLYNK_AUTH_TOKEN, WIFI_SSID, WIFI_PASSWORD);

timer.setInterval(3000L, mainTimer);

}

void loop() {

Blynk.run();

timer.run();

}

We made sure to properly read through the Blynk development platform documentation to get the better understanding of how this framework works and what widgets are available to us to develop the mobile application. We found that we are very limited when it comes to the variety of widgets, as we can only use Guage and Chart widgets. Based on that we developed very simple user interface, but at the same time we wanted to aim for great user experience, we came up with our own colour schemes to enhance the UI. After the whole team approved the Low-Fidelity prototype of the Blynk mobile application, we decided to move forward with the prototype and designed the Mid-Fidelity and the High-Fidelity prototype.

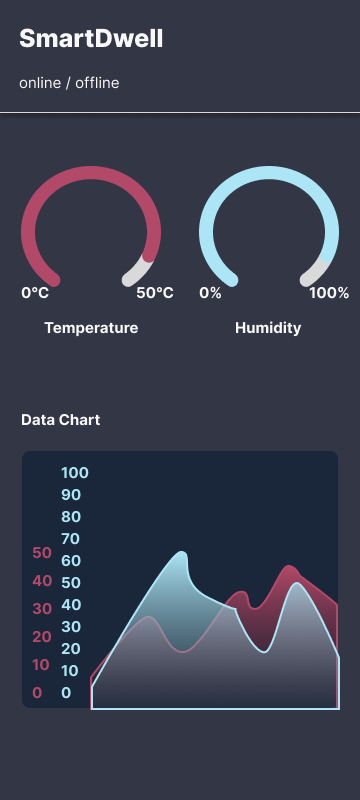
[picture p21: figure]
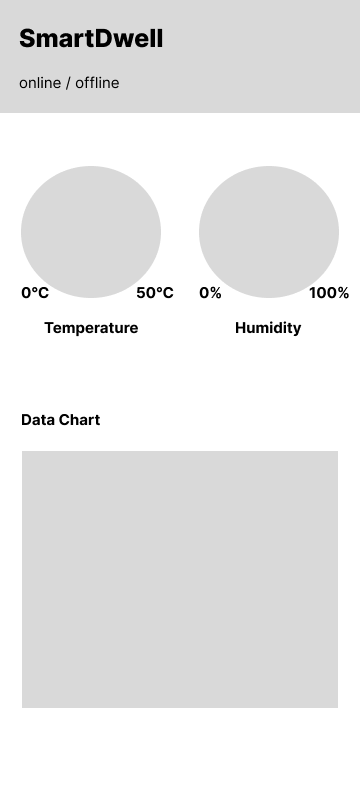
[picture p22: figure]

Picture 8 High-Fidelity Design

Picture 7 Mid-Fidelity Design

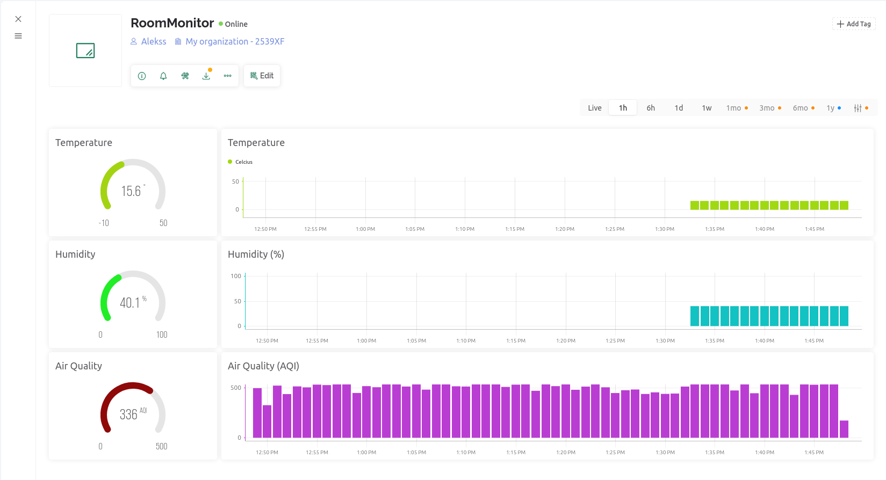
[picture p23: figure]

Picture 9 Web Dashboard

# 6. Testing approach

To test our room monitoring system we decided to test it in real life environment that is our accommodation. This would provide useful and accurate data that we will later use to calibrate and improve our entire system. We believe that this approach will be the most beneficial as it is closely related to the project’s targeted problematic.

For accurate testing we decided to use the following testing scheme:

Test case# | Title | Test Steps | Expected Result | Pass/Fail | Date
1 | Measure Temperature | 1. turn on device 2. wait | Temperature displayed in console | PASS | March 2024
2 | Measure Humidity | 1. turn on device 2. wait | Humidity displayed in console | PASS | March 2024
3 | Measure Air Quality Index | 1. turn on device 2. wait | Light value displayed in console | PASS | April 2024
4 | Connect and send data to API | 1. turn on device 2. wait | Blynk is showing the data received from device | PASS | April 2024
5 | Display current state through LCD display | 1. turn on device 2. wait | Temperature displayed on RGB LCD | PASS | April 2024
6 | Display current state on mobile app | 1. turn on device 2. open mobile app | Climate data displayed on mobile app | PASS | April 2024

# 7. Security Analysis

To prevent unauthorized breaches into our device we need to address two ways to access our device. Physical and remote. The physical part resembles the intruder physically connecting to the device via cable. This is prevented by enclosing the entire system in a 3D printed case assembled with screws. The intruder will not gain access to the device unless he is in possession of a screwdriver or will use excessive amount of force to damage or destroy the casing of the device to gain access to the Arduino YÚN ports.

Regarding the remote access the Arduino will be secured by the password, meaning that if by any chance the intruder would want to gain access to our device, he would firstly need to know the Wi-Fi password. Another way of defending against malicious thread is the implementation of authorization of the Blynk mobile application when connecting via secured Wi-Fi to Arduino YÚN. In the Arduino YÚN code we defined three very important lines of code, which are the Blynk Template ID, Blynk Template Name and mostly importantly the Blynk Authorization token, which represents the core of the authorization.

We made use of a ‘secrets.h’ file to store sensitive credentials used in the main code. A ‘.gitignore’ file is used to prevent the ‘secrets.h’ from being uploaded to github. We also included a ‘secrets.h-example’ file to show how the secrets file should be formatted. This prevents our sensitive credentials for Blynk, Wi-Fi, etc, from showing up on the internet.

# 8. Future Improvements

We plan to implement a second display that will be used to show the user forecast for the next 24 hours. This will expand the functionality of the device. To implement this, however, we will have to do some user testing before making this improvement to evaluate if this improvement will be useful in the long run.

The design of the case will also be updated to make the casing smaller and more convenient to put it into a regular household. In its current state the device cannot be mounted otherwise than just facing upwards laying down on the table. This will also be reworked as we plan to mount it to the wall.

Regarding the App design we plan to purchase a subscription plan for Blynk app development to widen our possibilities and make the app more functional than it is right now. We can also enhance the user experience by creating modern and pleasant user interfaces using the wide variety of widgets which are only available with subscription. Another approach would be to develop our own app from scratch using the previously mentioned flutter framework and Firebase real-time database with Firebase API. This will allow us to, as developers, to have more and almost full control of the entire life cycle of the app.

Other improvements include maintaining the device and keeping it up to date with security standards and other requirements.

# 9. List of images

Picture 9 Web Dashboard………………………………………………………. ……………………………………………………..18

# 10. Reference list

Noëlle Cotter, Eugene Monahan, Helen McAvoy, Patrick Goodman 2012, ‘Coping with the cold – exploring relationships between cold housing, health and social wellbeing in a sample of older people in Ireland’ emerald [Online]. Available from: https://www.emerald.com/insight/content/doi/10.1108/14717791211213607/full/html
[Viewed 8 March 2024].

Ahmad Roihan, Ferry Sudarto, Trengginas Cahyo Putro 2018, ‘Internet of Things on Monitoring and Control System in Server Area’ ieeexplore [Online]. Available from: https://ieeexplore.ieee.org/abstract/document/8549759
[Viewed 8 March 2024].

Academic Year: 2023/2024

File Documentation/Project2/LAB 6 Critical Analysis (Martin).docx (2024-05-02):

Internet of Things

Critical Analysis

bit.ly/3vTYAA2

Name | Martin Strelec
Date | 16/4/2024
Student No | S00256070
Student Email | s00256070@atu.ie

### Critical Analysis - see slides here (https://docs.google.com/presentation/d/193MMMz7EaoHWorLezZqeiO9gTh3cI20Jm06GoyJhtnw/edit?usp=sharing)


### 1. Draw the variables in your system in the format of a Bayesian Network

1. Draw the node you are trying to optimise in your system - e.g. OPTIMISE HYDRATION
2. Draw each node that will influence this dependent variable
3. Draw edges between nodes that influence each other
4. Calculate percentages of probabilities for each node (should add up to 100%)

### Individual Diagram

Notifications

Better sensors

Using mean instead of directly outputing values from sensors

Have a static placement for the device

Optimise accuracy of the readings

Group Diagram

Notifications

Better sensors

Using mean value instead of directly outputing values from sensors

Have a static placement for the device

Optimise accuracy of the readings

### What *effect* does your system have?

It has an effect on the living conditions and the health of the user

### On individuals?

It provides data analysis and control of individuals home and living space

### On society?

It will set a new standard for living conditions amongst all

### 2. Identify Assumptions

What assumptions did you make in designing your system?

Overall System | AI Elements of the system
1. Person’s health is affected by his living conditions 2. People are lazy or don’t have time 3. People want to live in healthier environment 4. People want a simple and cheap device | 1. Not using AI 2. Not using AI 3. Not using AI 4. Not using AI

### 3. Validate Assumptions

How could you check whether these assumptions are true?

Overall System | AI Elements of the system
1. Do a research 2. Do a survey 3. Do a research 4. Who wouldn’t want something simple and cheap? | 1. Not using AI 2. Not using AI 3. Not using AI 4. Not using AI

### 4. Reflect on New Assumptions

What new insights have you gained by identifying and validating your assumptions?

Overall System | AI Elements of the system
1. In most cases the mental health is based on your living conditions 2. People often want to improve their living conditions, but they don’t have time or they don’t care about it that much. 3. Most of the subjects agree to wanting to live in a healthier enviroment 4. Nothing changed here | 1. Not using AI 2. Not using AI 3. Not using AI 4. Not using AI

### 5. Consider Different Perspectives

How does your system design, ideas & actions look from Multiple Perspectives e.g. perspective people of different ages, different socio-economic backgrounds, different genders, different types of business people, different types of investors, different nationalities, differently abled people etc?

Overall System | AI Elements of the system
1. It should be easy to use for every user 2. It should be accessible to everyone not influenced by their financial state 3. It should be open-source so everyone can make changes and add features to their device 4. The parts should be cheap and easy to find | Not using AI

### 6. Imagine What-if Scenarios

Can you reimagine your system, or the environments and people using, it to unlock new creative possibilities? What do you imagine could be possible in the future?

Overall System | AI Elements of the system
1. Used in Retirement homes by caretakers 2. Used in Dormitories by students to demand service from the housing provider 3. Used in general households by enthusiasts and people who are interested in the product 4. Used in enterprise environment | Not using AI

### 7. Take Informed Action

Having gone through this Critical Analysis exercise, what would you change about your system and why?

Overall System | AI Elements of the system
1. Use different parts to make the making process even more enjoyable 2. Include a detailed manual to assemble and use the device 3. Make it more advanced and add more features 4. Enhance security | Not using AI

### 8. Draw a refined version of your BN Diagram from Step 1 - taking into account your Critical Analysis in Steps 2-7

5. Draw the node you are trying to optimise in your system
6. Draw each node that will influence this dependent variable
7. Draw edges between nodes that influence each other
8. Calculate percentages of probabilities for each node (should add up to 100%)

Quality

- not ideal: 70%

- ideal: 30%

Calibration

- proper calibration: 35%

- not calibrated: 65%

Our implementation

- good implementation: 85%

- bad implementation: 15%

Better Sensors

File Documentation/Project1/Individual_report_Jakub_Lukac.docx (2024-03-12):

Atlantic Technological University, Sligo

Obrázok, na ktorom je text, vizitka, snímka obrazovky, písmo Automaticky generovaný popis

# Individual Report

Name: Jakub Lukáč

Student ID: S00255726

Email: s00255726@atu.ie

Course: BSc in Software Development L7

Year: 1

Our group for the project on the course Internet of Things, consisted of me, Martin, and Alekss. We previously worked together during the 1st semester on the Designing Thinking project as well, so we have already developed a great understanding of each other in the technical area and in the personal and professional areas. We took our time with choosing the theme of our project as we wanted to be 100% sure we would be able to make that idea come through. At first, we had many great ideas, but after a few meetings and very careful consideration, we opted for the idea that was the most realistic one in terms of our free time and skills.

We decided to make a room monitoring system, for which we found many YouTube tutorials as well as official documentation, which made the process a bit easier for us. As previously mentioned, we understand each other well so far and each of us knows the other person’s strengths and weaknesses. We used that to our advantage and built the project around our skills. I took on the role of developing the mobile application for our Arduino project as I am very interested in developing mobile applications and, we thought it would be a great idea to give the consumers a nice visual representation of the data that the sensors gather.

So far, I am enjoying the process of developing the mobile application, as I am learning a new development platform, Blynk. Up to this point, I only developed mobile applications in Flutter, so I mark this as a big positive and a step forward for me in the mobile development environment. To be honest, my only disappointment is that Blynk offers very few widgets on the free version to build the mobile applications. Due to that I was very limited on how to approach the creation of the user interface.

We as a group function very well, each of us came on time for the meetings and all of us attended classes so we did not have any trouble with communication, which I am delighted with. The only thing that each of us should work on is updating the Trello page, which in future would mean uploading the work on the right place. Each of submitted the work on time or when they changed, they notified other members, but for all these actions we made mostly via social media or discord. With this I am trying to make a point that we should have transferred all the communication from social media and discord to purpose designed Trello page.

The only problem we faced was with the Blynk development environment as its library was too big for the Arduino YÚN storage space. But thanks to the skills each of us possesses we quickly came up with possible solutions to resolve this issue.

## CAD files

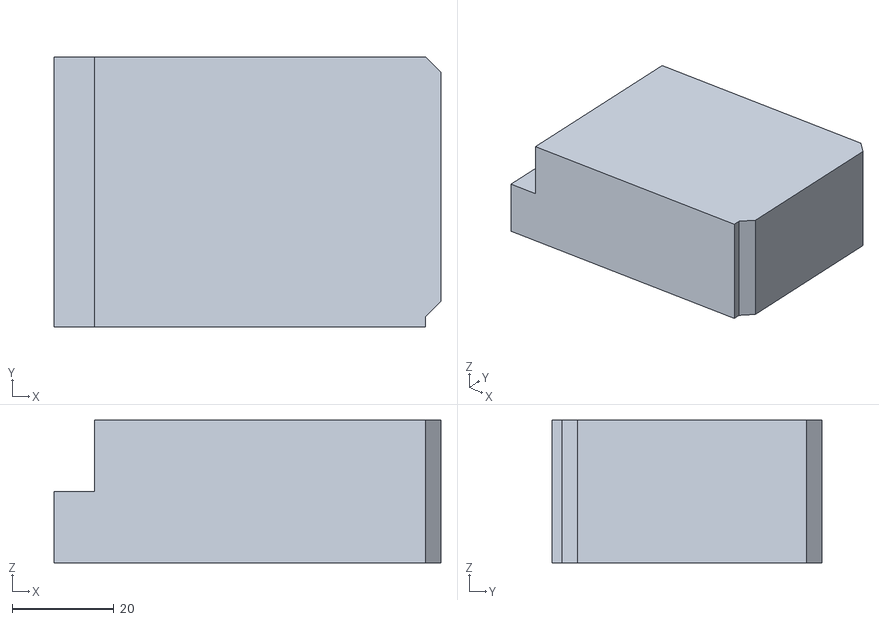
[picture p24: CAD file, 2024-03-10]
CaseDesign/ArduinoYUN.stl
76.0 x 53.0 x 28.0

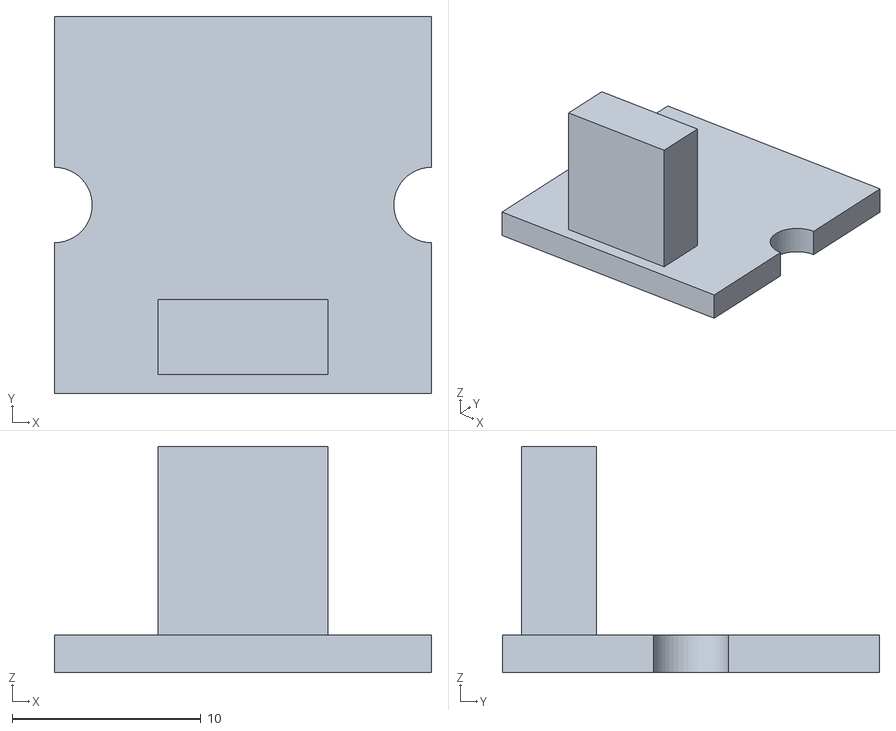
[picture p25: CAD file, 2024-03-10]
CaseDesign/GroveKIT_touchSensor.stl
20.0 x 20.0 x 12.0

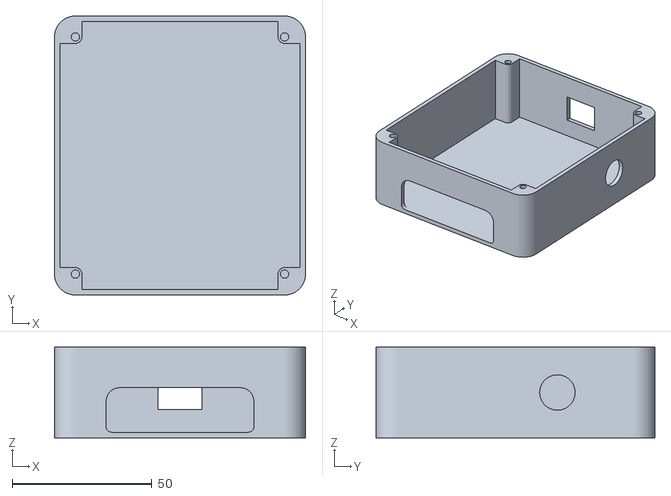
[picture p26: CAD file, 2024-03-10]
CaseDesign/Housing_Base.stl
90.0 x 100.0 x 32.5

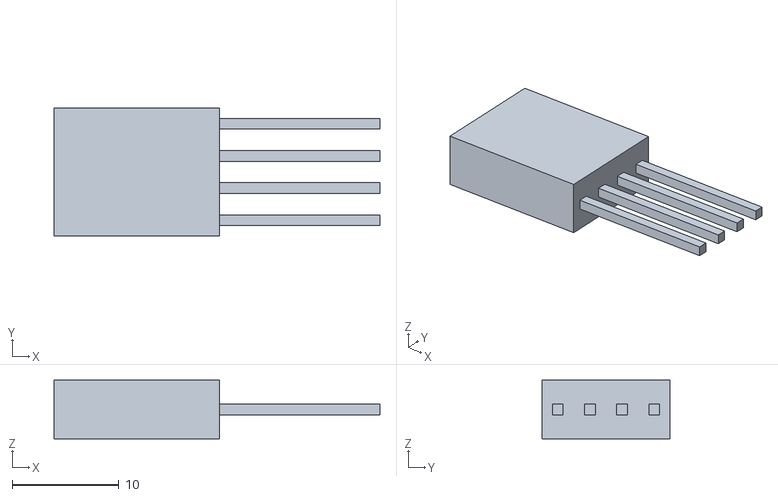
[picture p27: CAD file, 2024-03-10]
CaseDesign/DHT11_sensor.stl
30.5 x 12.0 x 5.50

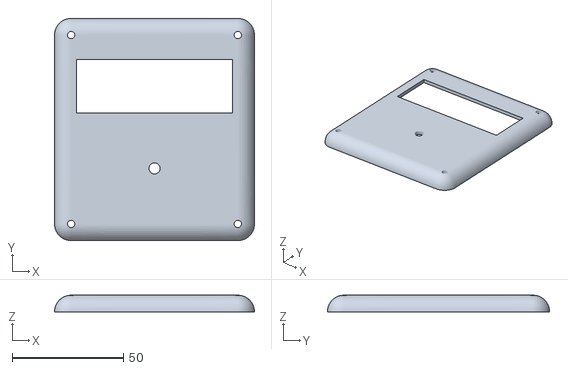
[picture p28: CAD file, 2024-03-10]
CaseDesign/Housing_TopCover.stl
90.0 x 100.0 x 7.50

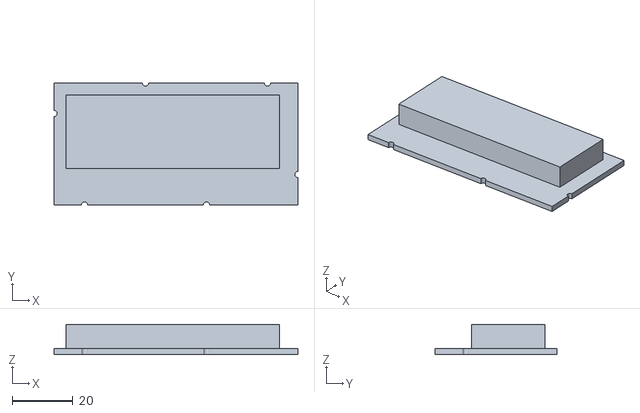
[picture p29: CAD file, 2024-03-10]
CaseDesign/LCD_display.stl
80.0 x 40.0 x 10.0

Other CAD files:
CaseDesign/Generic_GroveKIT_component.stl

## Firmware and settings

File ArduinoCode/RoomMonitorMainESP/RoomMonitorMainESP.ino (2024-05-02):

#define BLYNK_PRINT Serial 

#include "secrets.h"
#include <WiFi.h>
#include <WiFiClient.h>
#include <BlynkSimpleEsp32.h>
#include "esp_wpa2.h"
#include <DHT.h>
#include <Wire.h>
#include "rgb_lcd.h"
#include <math.h>

#define MQ135PIN A4  // Analog pin for MQ-135 air quality sensor
#define TEMPERATUREPIN 34   // Digital pin for temperature sensor
#define BUTTON_PIN 25  // Digital pin for button/rotary controller to control the RGB LCD


rgb_lcd lcd;
BlynkTimer timer;

uint8_t degreeSymbol[8] = { 0b11100, 0b10100, 0b11100, 0b00000, 0b00111, 0b00100, 0b00100, 0b00111 };

float analogTemp;
int celcius;
int airQuality;
int currentButtonState;
int lastButtonState;
int lcdState = LOW;

void setBacklightColour(float input, int min, int mid, int max) {
  int r, g, b;

  if (input <= min) {
    r = 0;
    g = 0;
    b = 255;
  } else if (input <= mid) {
    r = 0;
    g = map(input, min, mid, 0, 255);
    b = 255 - g;
  } else {
    r = 255;
    g = map(input, mid, max, 255, 0);
    b = 0;
  }

  lcd.setRGB(r, g, b);
}

int tempToCelcius(float analog) {
  const int B = 4275;               // B value of the thermistor
  const int R0 = 100000;            // R0 = 100k

  float R = 4095.0 / analog - 1.0;
  R = R0 * R;

  return 1.0 / (log(R / R0) / B + 1 / 278.15) - 273.15;
}

void printValueToLCD(int value, String title, String symbol, int min, int mid, int max) {
  lcd.clear();
  setBacklightColour(value, min, mid, max);
  lcd.setCursor(0, 0);
  lcd.print(title);
  lcd.setCursor(2, 1);
  lcd.print(value);
  lcd.setCursor(5, 1);
  lcd.print(symbol);
}

void mainTimer() {
  lastButtonState = currentButtonState;
  currentButtonState = digitalRead(BUTTON_PIN);

  analogTemp = analogRead(TEMPERATUREPIN);
  celcius = tempToCelcius(analogTemp);
  airQuality = analogRead(MQ135PIN);

  Blynk.virtualWrite(V2, celcius);
  Blynk.virtualWrite(V4, airQuality);

  if (lastButtonState == HIGH && currentButtonState == LOW) {
    if (lcdState == LOW) { 
      lcdState = HIGH; 
    } else { 
      lcdState = LOW; 
    }
  }

  if (lcdState == LOW) { 
    printValueToLCD(celcius, "Temperature", "\x03", -10, 18, 50); 
  } else { 
    printValueToLCD(airQuality, "Air Quality", " AQI", 0, 100, 1000); 
  }
}

String getWifiStatus(int status) {
  switch(status) {
    case WL_IDLE_STATUS: return "Wi-Fi Idle";
    case WL_SCAN_COMPLETED: return "Scan Completed";
    case WL_NO_SSID_AVAIL: return "No SSID";
    case WL_CONNECT_FAILED: return "Wi-Fi Failed";
    case WL_CONNECTION_LOST: return "Wi-Fi Lost";
    case WL_CONNECTED: return "Wi-Fi Connected";
    case WL_DISCONNECTED: return "Wi-Fi Init Bruv";
  }
}

void connectToWifi() {
  int status = WL_IDLE_STATUS;

  Serial.print("\nConnecting to network: ");
  Serial.println(WIFI_SSID);
  Serial.println(getWifiStatus(status));

  lcd.clear();
  lcd.setCursor(0, 0);
  lcd.print("Connecting to:");
  lcd.setCursor(0, 1);
  lcd.print(WIFI_SSID);
  delay(500);

  WiFi.disconnect(true);  // Disconnect from Wi-Fi to set new Wi-Fi connection
  WiFi.mode(WIFI_STA);  // Set Wi-Fi mode
  WiFi.begin(WIFI_SSID, WPA2_AUTH_PEAP, EAP_ANONYMOUS_IDENTITY, EAP_IDENTITY, EAP_PASSWORD); 
  // WiFi.begin(WIFI_SSID, WIFI_PASSWORD);

  int counter = 0;
  while (WiFi.status() != WL_CONNECTED) {
    if (counter++ >= 60) { ESP.restart(); }
    status = WiFi.status();
    Serial.print(getWifiStatus(status));

    lcd.clear();
    lcd.setCursor(0, 0);
    lcd.print(getWifiStatus(status));

    pinMode(BUTTON_PIN, INPUT);
    Serial.println("...");
    delay(500);
  }

  Serial.println("");
  Serial.println(F("Connected!"));
  Serial.println(F("Local ESP32 IP: "));
  Serial.println(WiFi.localIP());
}

void setup() {
  Serial.begin(115200);
  pinMode(BUTTON_PIN, INPUT);

  lcd.begin(16, 2, 0);
  lcd.setRGB(255, 255, 255);
  lcd.createChar(3, degreeSymbol);

  connectToWifi();
  lcd.clear();
  lcd.print("Blynking...");
  Blynk.begin(BLYNK_AUTH_TOKEN, WIFI_SSID, WIFI_PASSWORD);
  lcd.clear();
  lcd.print("Blynked!");
  currentButtonState = digitalRead(BUTTON_PIN);
  timer.setInterval(1000L, mainTimer);
}

void loop() {
  Blynk.run();
  timer.run();
}

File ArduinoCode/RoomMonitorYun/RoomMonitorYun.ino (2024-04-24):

#define BLYNK_TEMPLATE_ID           "TMPL4fnh6fOfH"
#define BLYNK_TEMPLATE_NAME         "TESTING"
#define BLYNK_AUTH_TOKEN            "euvMzHZrgcq9EjXGBV3cYtoN-rjmSNgo"

// #define BLYNK_TEMPLATE_ID "TMPL4rY8eAPdy"
// #define BLYNK_TEMPLATE_NAME "RoomMonitorTest"  
// #define BLYNK_AUTH_TOKEN "FbhVJkaUNkTJu4R2nffi3DF-MKS8qQ5M"

#define BLYNK_PRINT Serial

#define ROTARY_ANGLE_SENSOR A2

#include <Bridge.h>
#include <BlynkSimpleYun.h>
#include <Process.h>

#include <Wire.h>
#include "rgb_lcd.h"

BlynkTimer timer;

rgb_lcd lcd;

uint8_t degreeSymbol[8] = {
  0b11100,
  0b10100,
  0b11100,
  0b00000,
  0b00111,
  0b00100,
  0b00100,
  0b00111,
};

int celcius;
int humidity;
int airQuality;
int rotary = 0;


BLYNK_WRITE(V0) {
  int value = param.asInt();
  Blynk.virtualWrite(V1, value);
}

void myTimerEvent() {
  Blynk.virtualWrite(V2, celcius);
  // Blynk.virtualWrite(V3, humidity);
  // Blynk.virtualWrite(V4, airQuality);
}


void setup() {
    pinMode(ROTARY_ANGLE_SENSOR, INPUT);
    Serial.begin(115200);

    Bridge.begin();  // make contact with the linux processor
    Blynk.begin(BLYNK_AUTH_TOKEN);  // You can also specify server:

    timer.setInterval(1000L, myTimerEvent);
    
    lcd.begin(16, 2, 0);
    lcd.setRGB(0, 255, 0);
    lcd.createChar(3, degreeSymbol);
    Serial.println("SETUP DONE");
}

void setBacklightColour(float input, int min, int mid, int max) {
    int r, g, b;

    if (input <= min) {
        r = 0;
        g = 0;
        b = 255;
    } else if (input <= mid) {
        r = 0;
        g = map(input, min, mid, 0, 255);
        b = 255 - g;
    } else {
        r = 255;
        g = map(input, mid, max, 255, 0);
        b = 0;
    }

    lcd.setRGB(r, g, b);
}

int tempToCelcius(float temp) {
  const int BETA = 3975;
  float resistance = (float)(1023 - temp) * 10000 / temp;  // get sensor's resistance
  return 1 / (log(resistance / 10000) / BETA + 1 / 298.15) - 273.15;  // convert to temperature via datasheet&nbsp;
}

void printValueToLCD(int value, String title, String symbol, int min, int mid, int max) {
    setBacklightColour(value, min, mid, max);
    lcd.setCursor(0, 0);
    lcd.print(title);
    lcd.setCursor(2, 1);
    lcd.print(value);
    lcd.setCursor(5, 1);
    lcd.print(symbol);
}

void loop() {
    Blynk.run();
    timer.run();

    rotary = analogRead(ROTARY_ANGLE_SENSOR);
    Serial.println(rotary);

    if (rotary < 150) {
        celcius = tempToCelcius(analogRead(A0));
        printValueToLCD(celcius, "Temperature", "\x03", -10, 15, 40);
        
        
    }
    else if (rotary >= 150) {
        // int humidity = analogRead(A1);
        humidity = 54;
        printValueToLCD(humidity, "Humidity", "%", 0, 50, 100);
    }

    delay(1000);
    lcd.clear();
}

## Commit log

2024-03-10 Added 3D files for the housing
    [ArduinoYUN.stl, DHT11_sensor.stl, Generic_GroveKIT_component.stl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]
2024-03-12 Added arduino code
2024-03-12 Added RGB temperature tester
2024-04-24 Added room monitor code for ESP32
2024-04-24 Added room monitor code for ESP32 (test)
2024-04-25 added sensor code
